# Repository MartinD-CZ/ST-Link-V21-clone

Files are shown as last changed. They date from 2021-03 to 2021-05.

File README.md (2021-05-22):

# ST-Link V2.1 USB dongle
This is an ST-Link V2.1 in the form of an USB dongle, similar to those available from any Chinese store. However, the IDC connector has different pinout, with the following pins available:
- +5 V and +3.3 V, each up to 500 mA
- TPWR for measuring target voltage or future optoisolators
- GND
- SSWCLK, SWDIO, NRST for programming/debugging
- SWO for SW Trace functionality
- RX/TX for VCP (Virtual Com Port)

[**MORE INFO**](http://embedblog.eu/?p=780)

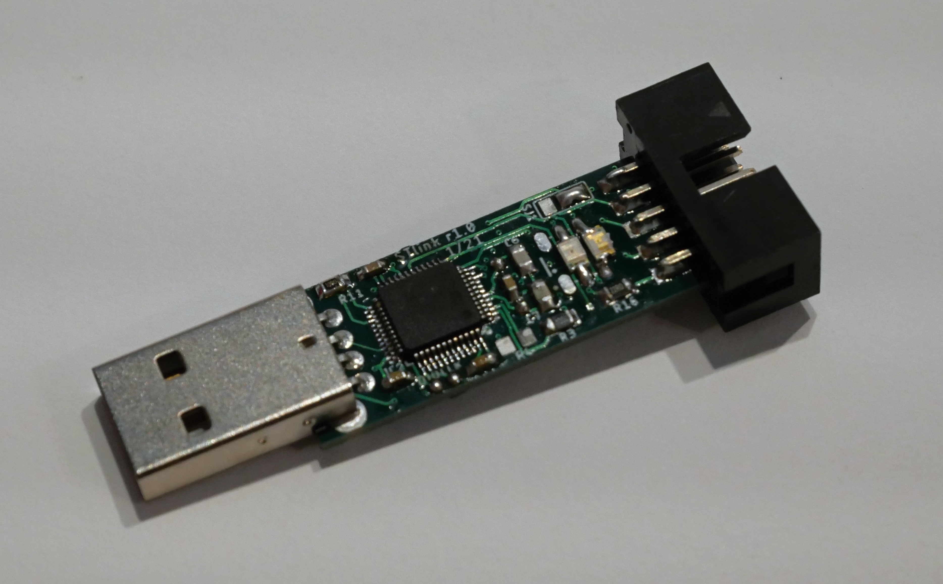
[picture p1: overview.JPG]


### Update 05/21
I've made another version, this time with an SMD crystal and a microUSB connector - it's marked as rev10D.

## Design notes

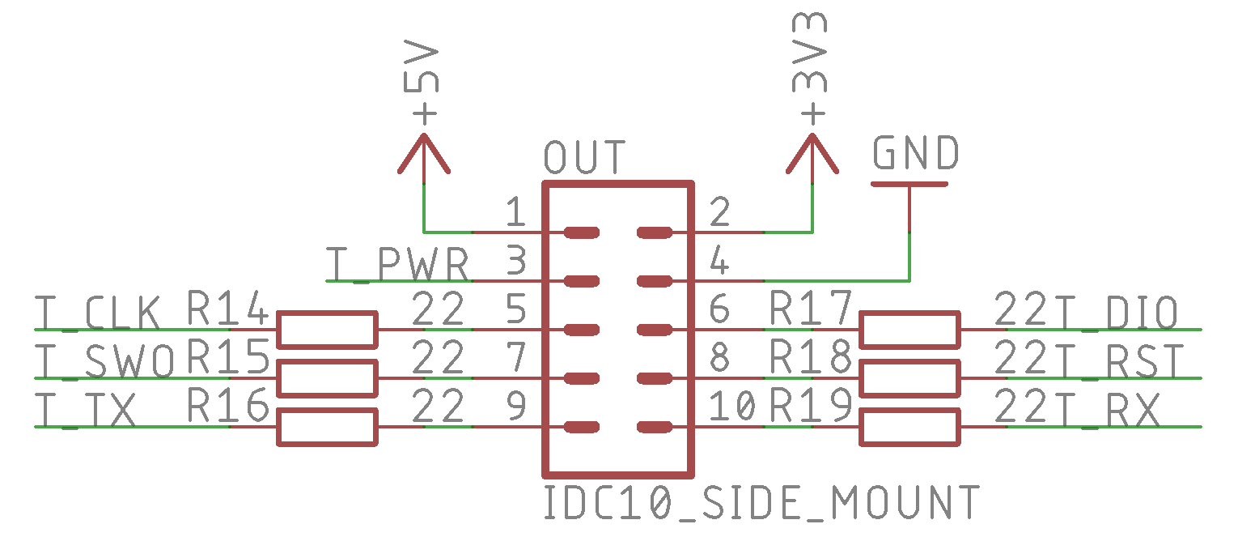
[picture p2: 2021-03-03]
HW/stlink_schematics_connector.png

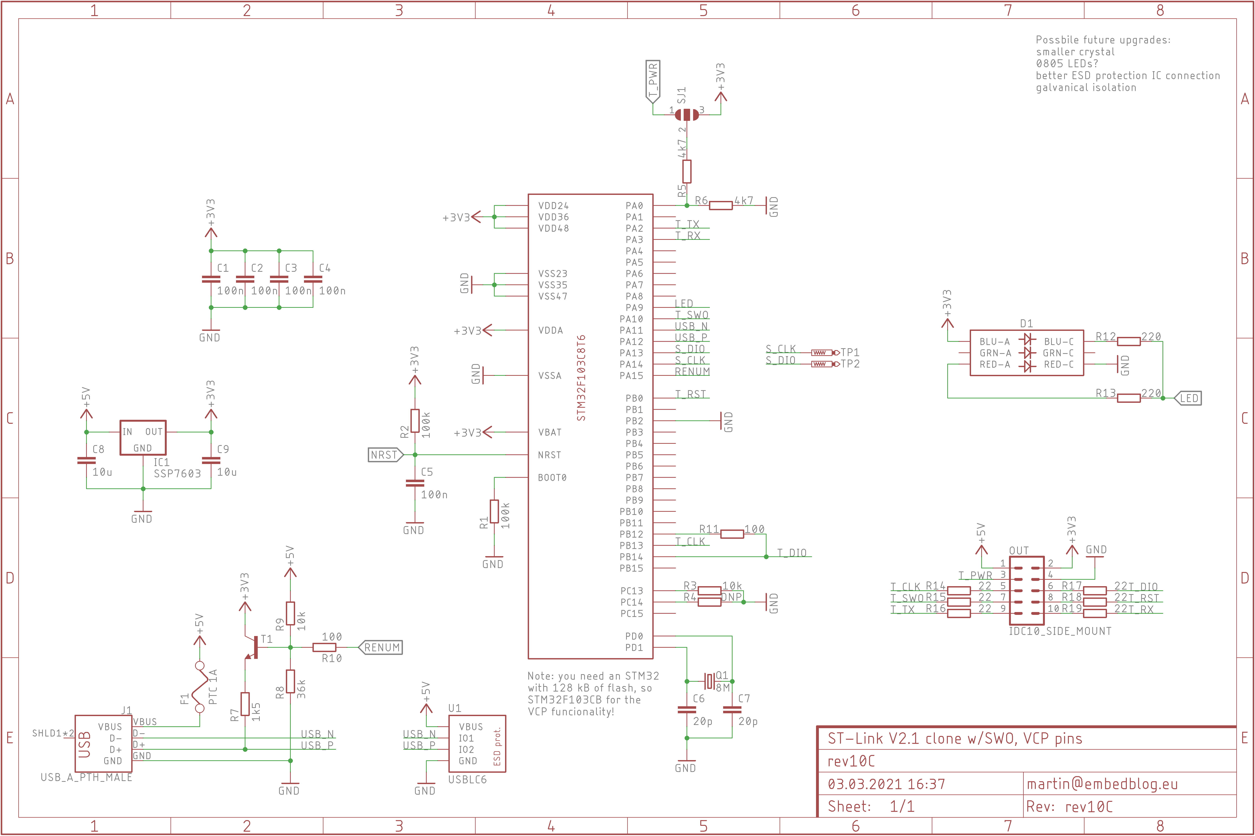
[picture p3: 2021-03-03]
HW/stlink_schematics_r10C.png

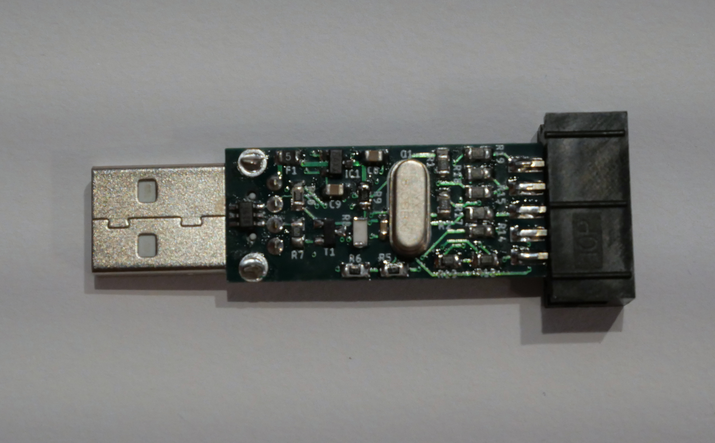
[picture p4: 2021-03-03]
bottom.JPG

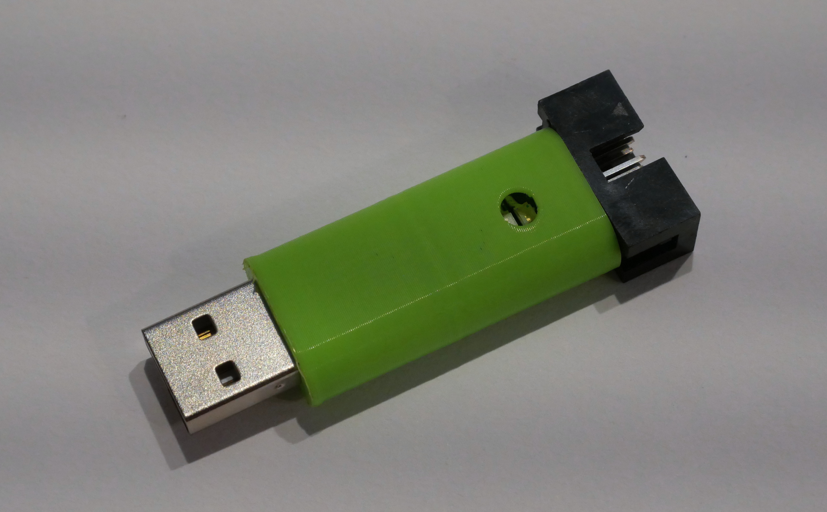
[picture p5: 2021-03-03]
final.JPG

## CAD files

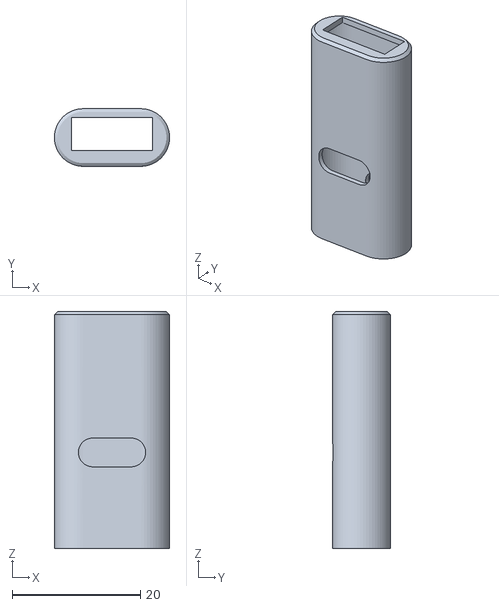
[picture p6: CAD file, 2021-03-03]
HW/STlink_case.stl
18.0 x 9.00 x 37.0

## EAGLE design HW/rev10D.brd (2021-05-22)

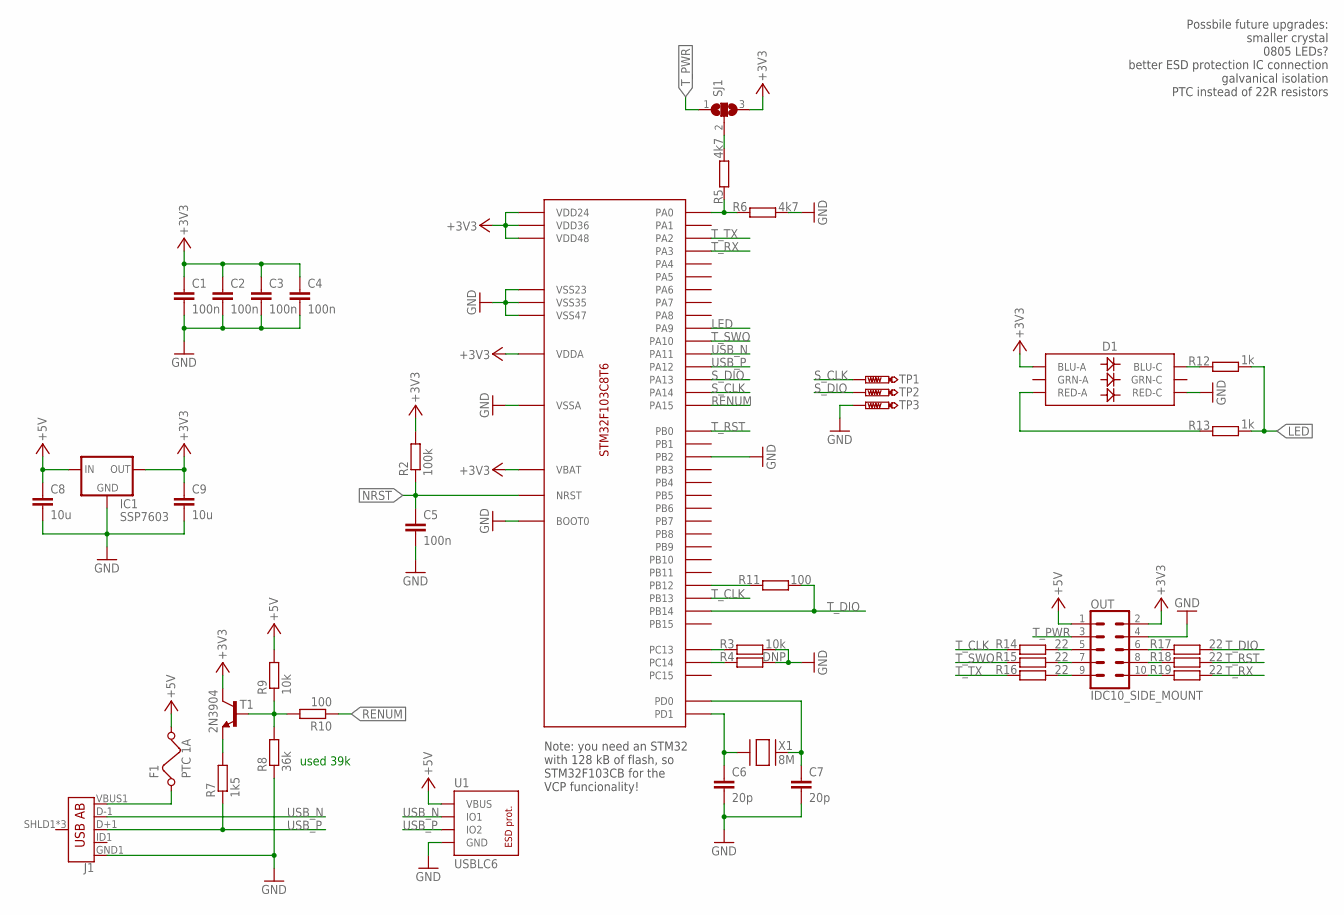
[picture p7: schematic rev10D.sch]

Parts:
C1, C2, C3, C4, C5: 100n; C0603
C6, C7: 20p; C0805
C8, C9: 10u; C0805
D1: LED-RGBNO_IC; LED-TRICOLOR-5050
F1: PTC 1A; 0805
IC1: SSP7603; SOT23
IC2: STM32F103C8T6; TQFP-48
J1: USB_AB_SMT; USB-AB-MICRO-SMD
OUT: IDC10_SIDE_MOUNT; IDC10_SIDEWAYS
R2: 100k; R0805
R3, R9: 10k; R0805
R4: DNP; R0805
R5, R6: 4k7; R0805
R7: 1k5; R0805
R8: 36k; R0805
R10, R11: 100; R0805
R12, R13: 1k; R0805
R14, R15, R16, R17, R18, R19: 22; R0805
SJ1: SJ2W; SJ_2
T1: 2N3904; SOT23-BEC
TP1, TP2, TP3: PTR1B1,27; B1,27
U1: USBLC6; SOT23-6
X1: 8M; NX5032

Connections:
+3V3: C1.1, C2.1, C3.1, C4.1, C9.1, D1.3 (BLU-A), IC1.2 (OUT), IC2.1 (VBAT), IC2.9 (VDDA), IC2.24 (VDD24), IC2.36 (VDD36), IC2.48 (VDD48), OUT.2, R2.2, SJ1.3, T1.C
+5V: C8.1, F1.2, IC1.3 (IN), OUT.1, R9.2, U1.5 (VBUS)
GND: C1.2, C2.2, C3.2, C4.2, C5.2, C6.2, C7.2, C8.2, C9.2, D1.5 (RED-C), IC1.1 (GND), IC2.8 (VSSA), IC2.20 (PB2), IC2.23 (VSS23), IC2.35 (VSS35), IC2.44 (BOOT0), IC2.47 (VSS47), J1.GND1 (GND), OUT.4, R3.1, R4.1, R6.1, R8.1, TP3.TP, U1.2 (GND)
LED: IC2.30 (PA9), R12.1, R13.1
unnamed: IC2.3 (PC14), R4.2
unnamed: IC2.25 (PB12), R11.2
unnamed: IC2.2 (PC13), R3.2
unnamed: C6.1, IC2.6 (PD1), X1.P$1
unnamed: C7.1, IC2.5 (PD0), X1.P$2
unnamed: R7.2, T1.E
unnamed: IC2.10 (PA0), R5.2, R6.2
unnamed: F1.1, J1.VBUS1 (VBUS)
unnamed: R8.2, R9.1, R10.2, T1.B
unnamed: D1.2 (RED-A), R13.2
unnamed: D1.4 (BLU-C), R12.2
unnamed: R5.1, SJ1.2
unnamed: OUT.5, R14.1
unnamed: OUT.7, R15.1
unnamed: OUT.9, R16.1
unnamed: OUT.6, R17.2
unnamed: OUT.8, R18.2
unnamed: OUT.10, R19.2
NRST: C5.1, IC2.7 (NRST), R2.1
RENUM: IC2.38 (PA15), R10.1
S_CLK: IC2.37 (PA14), TP1.TP
S_DIO: IC2.34 (PA13), TP2.TP
T_CLK: IC2.26 (PB13), R14.2
T_DIO: IC2.27 (PB14), R11.1, R17.1
T_PWR: OUT.3, SJ1.1
T_RST: IC2.18 (PB0), R18.1
T_RX: IC2.13 (PA3), R19.1
T_SWO: IC2.31 (PA10), R15.2
T_TX: IC2.12 (PA2), R16.2
USB_N: IC2.32 (PA11), J1.D-1 (D-), U1.1 (IO1), U1.6 (IO1)
USB_P: IC2.33 (PA12), J1.D+1 (D+), R7.1, U1.3 (IO2), U1.4 (IO2)

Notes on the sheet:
Possbile future upgrades: smaller crystal 0805 LEDs? better ESD protection IC connection galvanical isolation PTC instead of 22R resistors
Note: you need an STM32 with 128 kB of flash, so STM32F103CB for the VCP funcionality!
used 39k

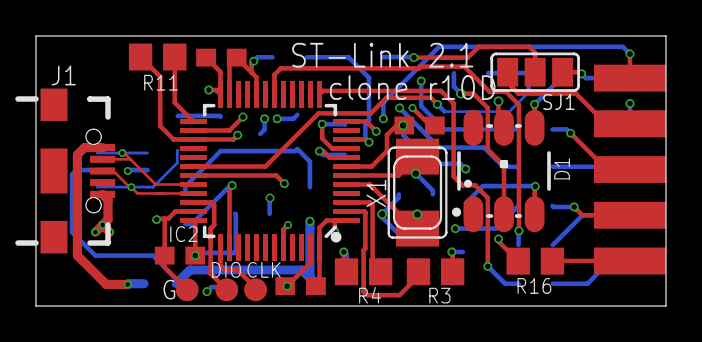
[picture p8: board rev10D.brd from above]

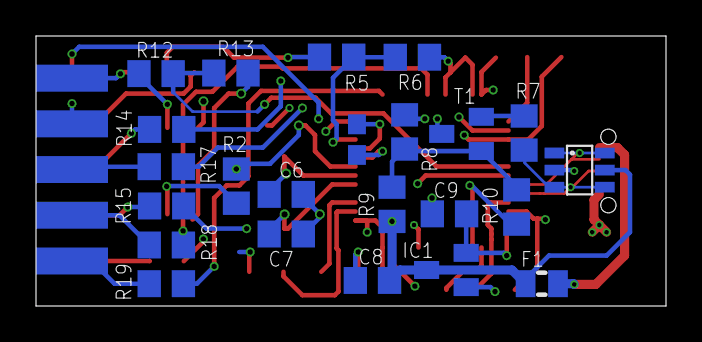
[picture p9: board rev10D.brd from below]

Board: 4 copper layers, 35.0 x 15.0 mm, 40 parts (23 on the bottom side), 35 nets.

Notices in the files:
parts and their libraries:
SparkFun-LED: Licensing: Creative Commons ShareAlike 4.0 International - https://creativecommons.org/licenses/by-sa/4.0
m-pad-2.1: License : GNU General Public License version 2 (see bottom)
